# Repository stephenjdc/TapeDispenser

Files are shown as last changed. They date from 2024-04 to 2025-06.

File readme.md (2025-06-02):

# Kilnettle Shrine Souvenir Tape Dispenser



Blog post: https://stephencoyle.net/kilnettle

If you'd like to build your own [tape dispenser](https://stephencoyle.net/kilnettle), which tells you how much you've used, and blesses you afterwards, you have two choices.

1. Leave out a pencil and paper one night before bed, and hope that by the morning God will have written down the instructions.
2. Buy one from me. Maybe? Details coming soon(?)
3. Clone this repo, buy the required parts, a 3D printer, and get to work. [Here's an assembly tutorial](https://youtu.be/CnwMDydeqiA).

Please note that, while the dispenser does aim to fairly accurate, it's not perfectly accurate as it doesn't adjust for the amount of tape used. In the code I've just split the error, so it will tend to overshoot the measurement when a roll is full, and undershoot a bit when it's empty. Given we're only dealing with one-inch resolution, I feel like it's probably fine. You can tweak the code if you want to try and improve on this. There's also is a no-code way to tweak it, detailed below.

## License 
Feel free to make/reuse/modify this project for personal use. In the unlikely event that you're planning to spin up a large-scale production line to make thousands of these, I'd really recommend doing a few more revisions on the code and the models. In which case, I'm available at a very reasonable rate.

## Parts list

### Electronics
- 1× ESP8266 or similar (e.g. I used an ESP-12E)
- 1× IR photodiode (3mm)
- 1× IR LED (3mm)
- 2× 1k resistors
- 2× 10k resistors
- 1× 220Ω resistor
- 1× 2N3904 transistor (or similar)
- 1× LED (colour of your choice, I recommend red)
- 1× 20mm diameter speaker
- 1× 18mm × 12mm slide switch (or any that fits the space on the model)
- Battery clips for 2x AAA batteries

There are included KiCAD files which you can use to create a PCB for this, but point-to-point soldering can also work if you don't want to do that.

#### PCB Legend
| PCB Label | Component | Description |
|---|---|---|
| `R1` | `1K resistor` | |
| `R2` | `220R resistor` | |
| `R3` | `1K resistor` | |
| `R4` | `10K resistor` | |
| `R5` | `10K resistor` | |
| `D1` | `Photodiode` | Small black LED |
| `D2` | `IR LED` |  Small clear LED |
| `D3` | `Indicator LED` | Red LED |
| `LS1` | `Speaker` |  |
| `Q1` | `2N3904 Transistor` |  |
| `U1` | `ESP8266` |  |
| `J1` | `GND` |  |
| `J2` | `+3V` | |

### Dispenser body
#### These parts are 3D-printable (in the models folder)
- 1× tape dispenser body
- 1× tape dispenser lid (which holds the spool)
- 1× battery compartment cover
- 1× tape spool
- 1× "Greetings from Kilnettle" text

#### These parts are not 3D printable
- 1× 33mm × 5mm hacksaw blade (for tape cutter)
- 1x 25mm × 1mm steel rod (for example, cut from a large paperclip)
- 2× AAA batteries
- 1x roll of sticky tape with ~27mm inner diameter and ~56mm outer diameter. I used [this one](https://firstclassofficesupplies.com/product/stik-ie-clear-tape-refills/).

## Instructions
I'm gonna keep these fairly sparse, and following what I did. But there's no right way to do it. In the very unlikely event that you actually want to make one yourself, and run into trouble, feel free to message me with any questions. The [video version](https://youtu.be/CnwMDydeqiA) may also be more useful!

1. Flash the ESP-12E with the included sketch, _and data folder_. I used PlatformIO and would suggest you do too.
2. 3D print the included files.
3. Insert the battery clips into the slots in the battery container. Note which side has holes for the positive and negative tabs to slot into.
4. Fit the slider switch into the hole above the battery compartment. Either glue into place, or like I did, use a soldering iron to melt and smush the little nubs to fix it in place.
5. Fit the IR photodiode and LED into the holes on the sides of the lid. They should be a fairly tight fit; push them all the way in. I added a little drop of superglue to keep them fixed in place.
6. Add the speaker. It should click into place at the front of the body, though I added a little hot glue just to be sure. If you aren't using the PCB, it might be easier to add the transistor and resistor on or near the speaker itself, then tuck all that in with the speaker.
7. Solder some wires to the battery tabs and switch.
8. Follow the rest of the schematic to attach all the parts. If you aren't using the PCB, use the thinnest wire you feasibly can, and route the wires as best you can to allow the case to close. I'd recommend leaving a decent bit of slack, and regularly trying to fit the lid on to make sure all is fitting well.
9. Once that's done, I'd recommend testing it out[^1], so you can check the software is flashed properly before you finish fitting things into place.
10. Pop on the lid, if you're happy everything is working. The tabs at the back should clip into place in the case.
11. Superglue the section of hacksaw blade in place on the front of dispenser. Make sure to put the sharper side facing up, if there is one, so it cuts the tape nicely.
12. Attach the "Greetings from Kilnettle" text to the left side of the dispenser body (left when looking at the bladed end).
13. For the spool, thread the steel rod through the hole in its centre. Add a drop of glue and line it up so that it protrudes an equal amount on either side. It should then press fit into the tape, and you can set it into the dispenser.
14. Insert batteries (be careful to put them in the right way round), pop on the battery cover, and all being well, you should now be able to switch it on and enjoy your dispenser!

[^1]: You can easily test it without a spool, by waving your finger around in the spool cavity, making sure you block the IR beam a few times.

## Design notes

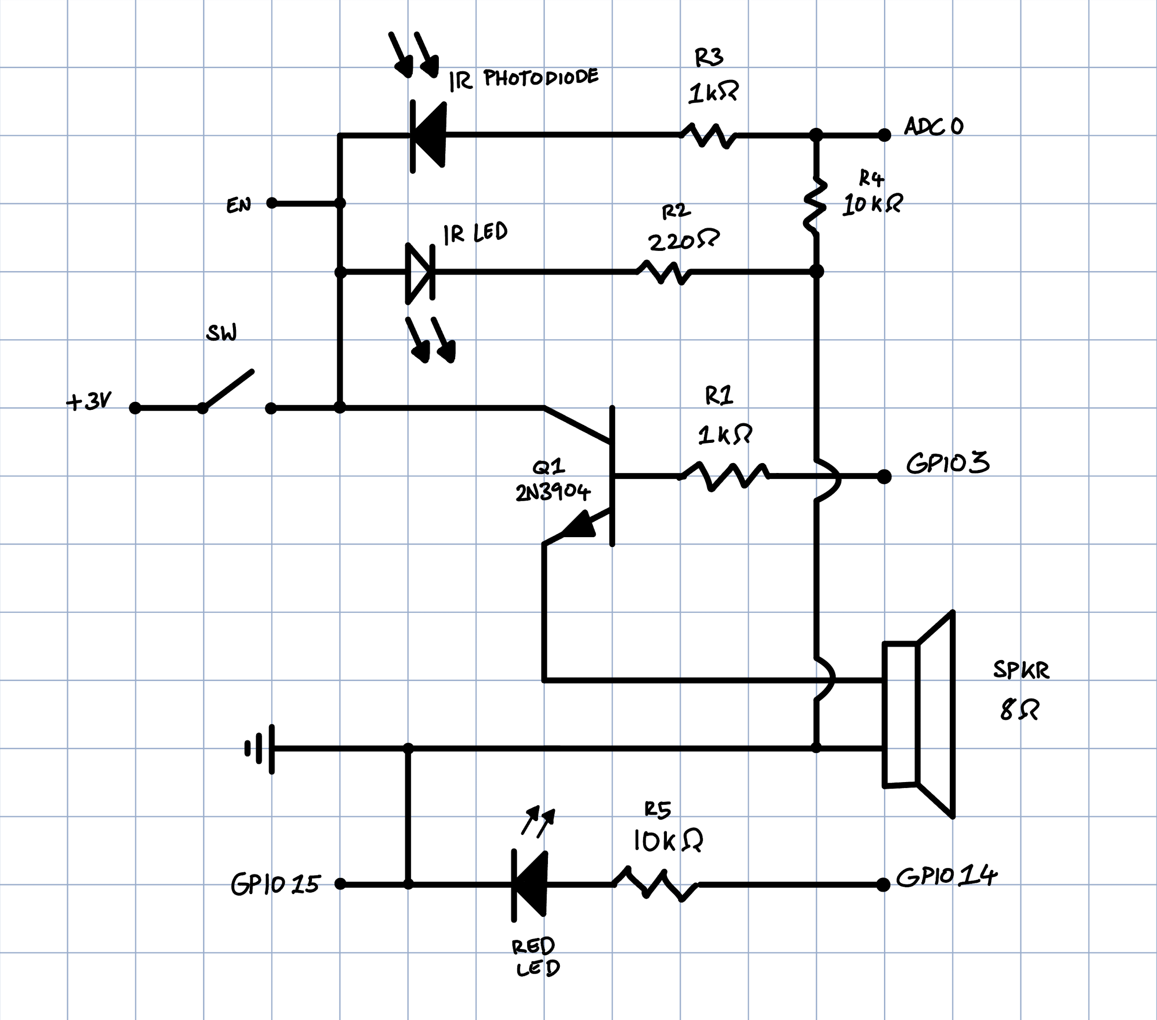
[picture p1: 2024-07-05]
pcb/schematic.png

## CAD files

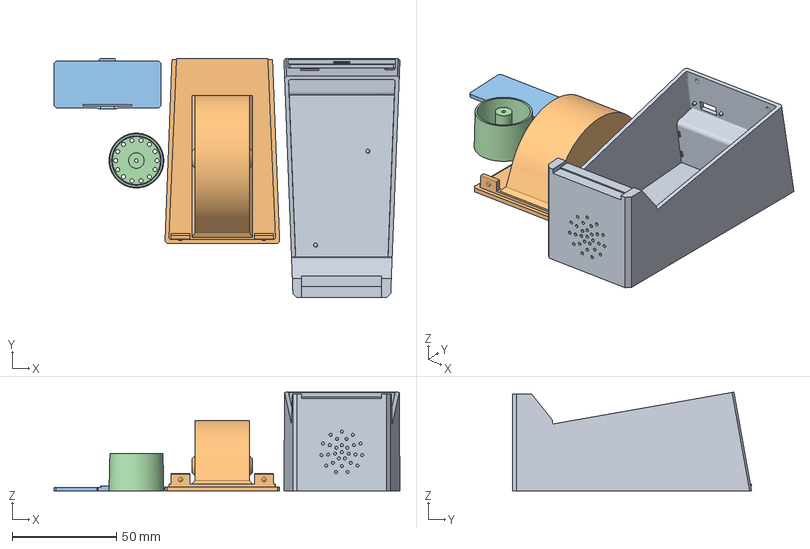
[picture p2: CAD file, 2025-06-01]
models/v2_models/All Parts Excl Text.3mf
166.2 x 115.0 x 47.5 mm
body_v3.stp
lid.stp
battery_door_v3.stp
spool.stp

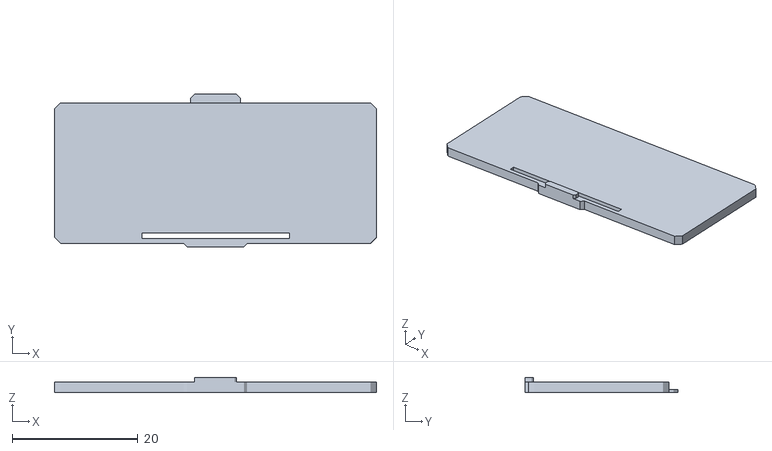
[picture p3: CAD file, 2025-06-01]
models/v2_models/battery_door.stl
51.3 x 24.3 x 2.36

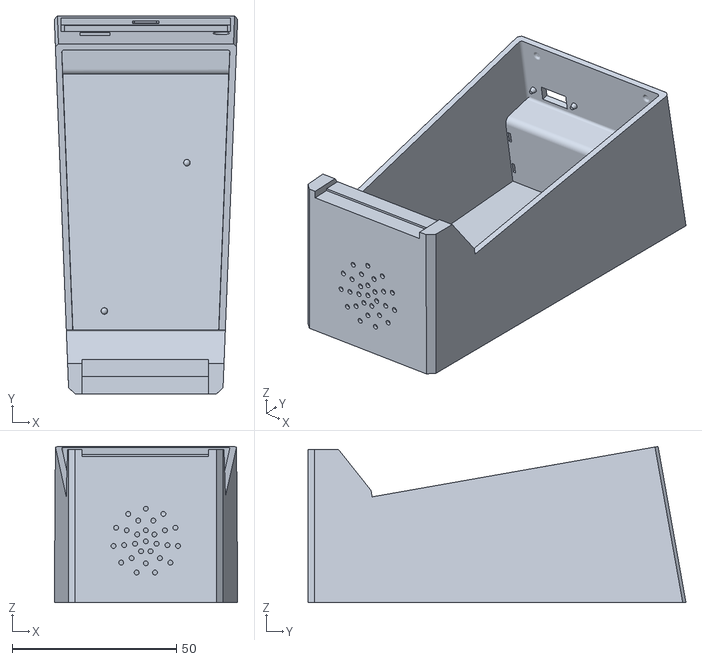
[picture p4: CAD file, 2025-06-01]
models/v2_models/body.stl
55.8 x 115.0 x 47.5

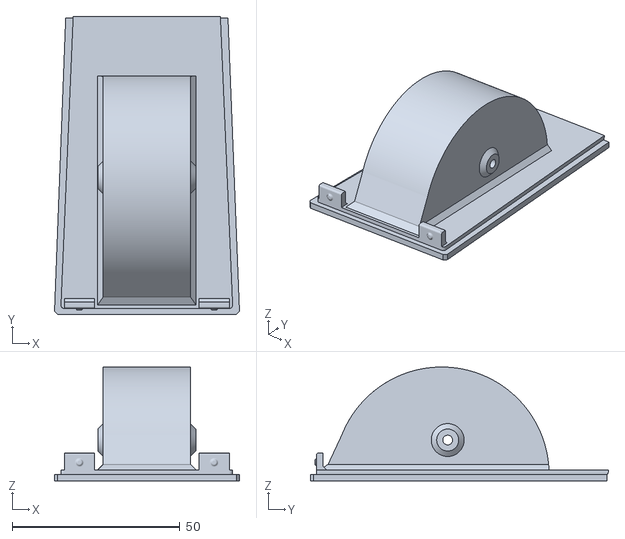
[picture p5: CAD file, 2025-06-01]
models/v2_models/lid.stl
55.1 x 88.9 x 33.9

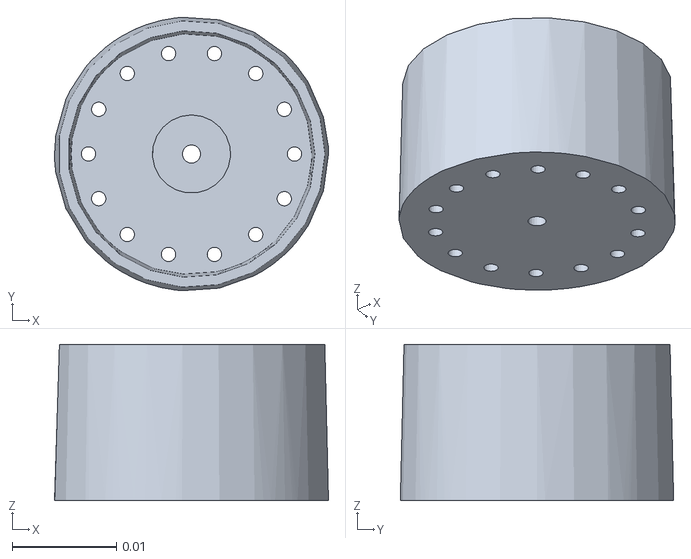
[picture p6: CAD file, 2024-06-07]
models/v2_models/spool.stl
0.0263 x 0.0262 x 0.015

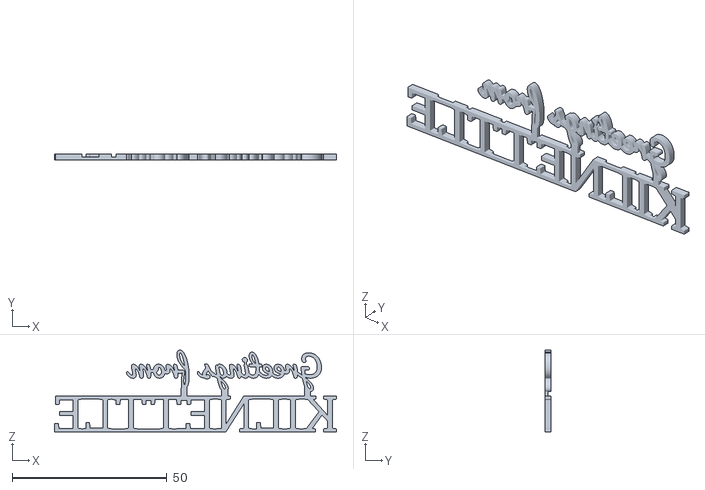
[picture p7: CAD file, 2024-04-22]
models/v2_models/greetings_text.stl
91.1 x 2.00 x 26.5

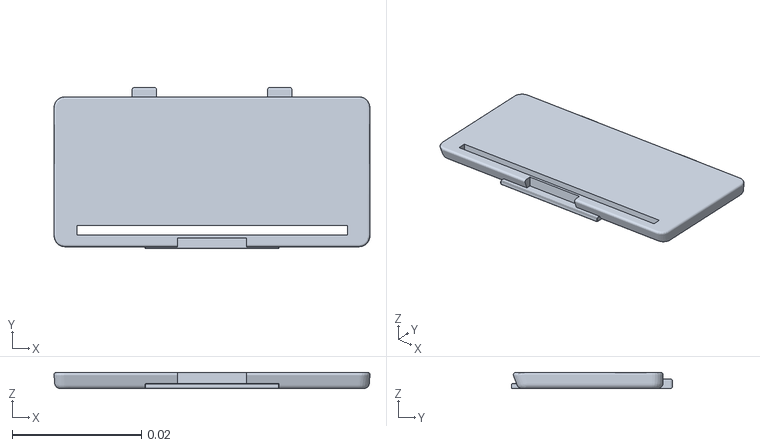
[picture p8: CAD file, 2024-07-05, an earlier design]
models/v1_models/battery_door.stl
0.0488 x 0.0249 x 0.0025

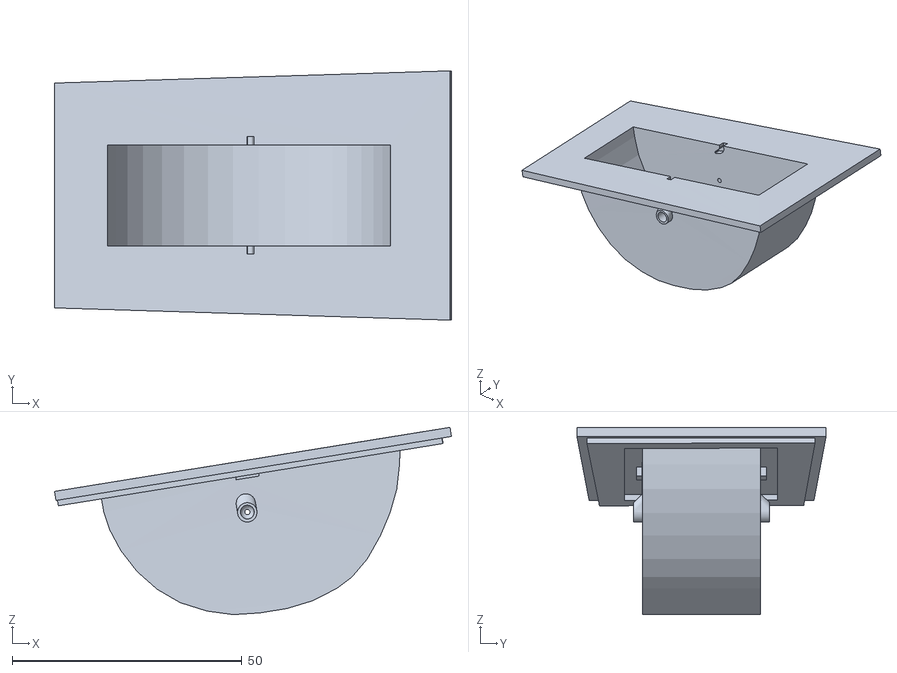
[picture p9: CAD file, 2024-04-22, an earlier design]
models/v1_models/dispenser_lid.stl
86.4 x 54.2 x 40.7

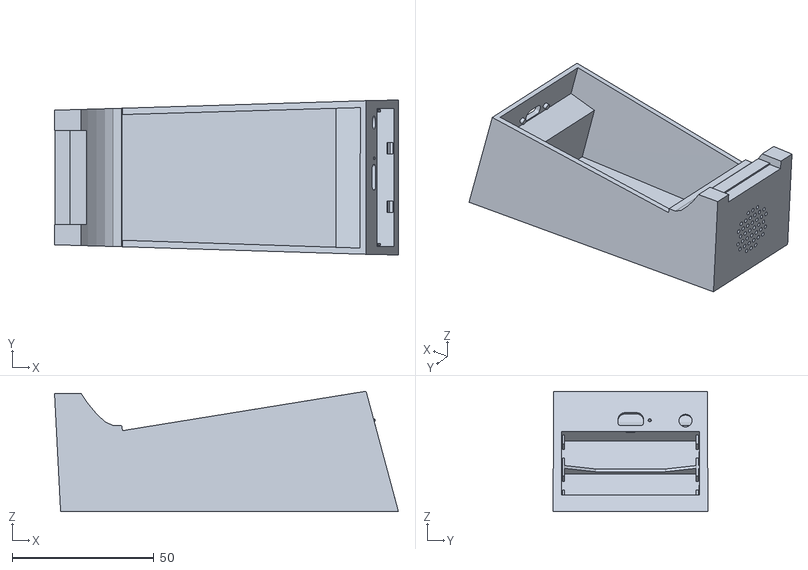
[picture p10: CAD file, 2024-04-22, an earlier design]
models/v1_models/dispenser_body.stl
121.5 x 54.7 x 42.5

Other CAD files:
models/v1_models/spool_13.stl
models/v1_models/spool_16.stl
models/v1_models/spool_15.stl

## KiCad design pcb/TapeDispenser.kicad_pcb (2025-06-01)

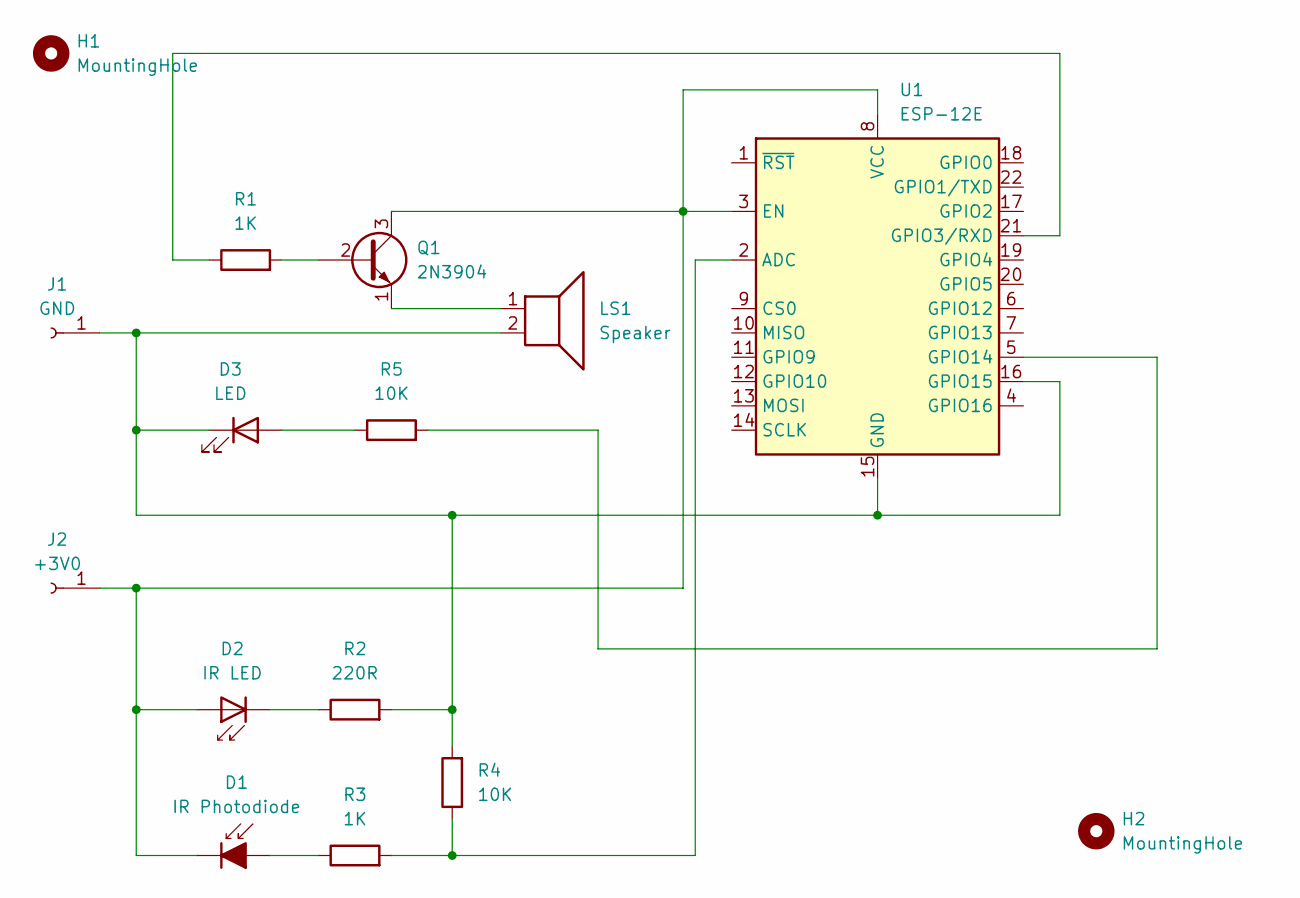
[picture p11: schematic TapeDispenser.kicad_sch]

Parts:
D1: IR Photodiode; SolderWire-0.5sqmm_1x02_P4.6mm_D0.9mm_OD2.1mm
D2: IR LED; SolderWire-0.5sqmm_1x02_P4.6mm_D0.9mm_OD2.1mm
D3: LED; SolderWire-0.5sqmm_1x02_P4.6mm_D0.9mm_OD2.1mm
H1, H2: MountingHole; MountingHole_2.2mm_M2
J1: GND; SolderWire-0.5sqmm_1x01_D0.9mm_OD2.1mm
J2: +3V0; SolderWire-0.5sqmm_1x01_D0.9mm_OD2.1mm
LS1: Speaker; SolderWire-0.5sqmm_1x02_P4.6mm_D0.9mm_OD2.1mm
Q1: 2N3904; TO-92_Inline
R1, R3: 1K; R_Axial_DIN0207_L6.3mm_D2.5mm_P10.16mm_Horizontal
R2: 220R; R_Axial_DIN0207_L6.3mm_D2.5mm_P10.16mm_Horizontal
R4, R5: 10K; R_Axial_DIN0207_L6.3mm_D2.5mm_P10.16mm_Horizontal
U1: ESP-12E

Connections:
unnamed: D1.2 (A), R3.1
unnamed: D1.1 (K), D2.2 (A), J2.1, Q1.3 (C), U1.3 (EN), U1.8 (VCC)
unnamed: D2.1 (K), R2.1
unnamed: D3.2 (A), R5.1
unnamed: D3.1 (K), J1.1, LS1.2, R2.2, R4.2, U1.15 (GND), U1.16 (GPIO15)
unnamed: Q1.2 (B), R1.2
unnamed: LS1.1, Q1.1 (E)
unnamed: R3.2, R4.1, U1.2 (ADC)
unnamed: R1.1, U1.21 (GPIO3/RXD)
unnamed: R5.2, U1.5 (GPIO14)

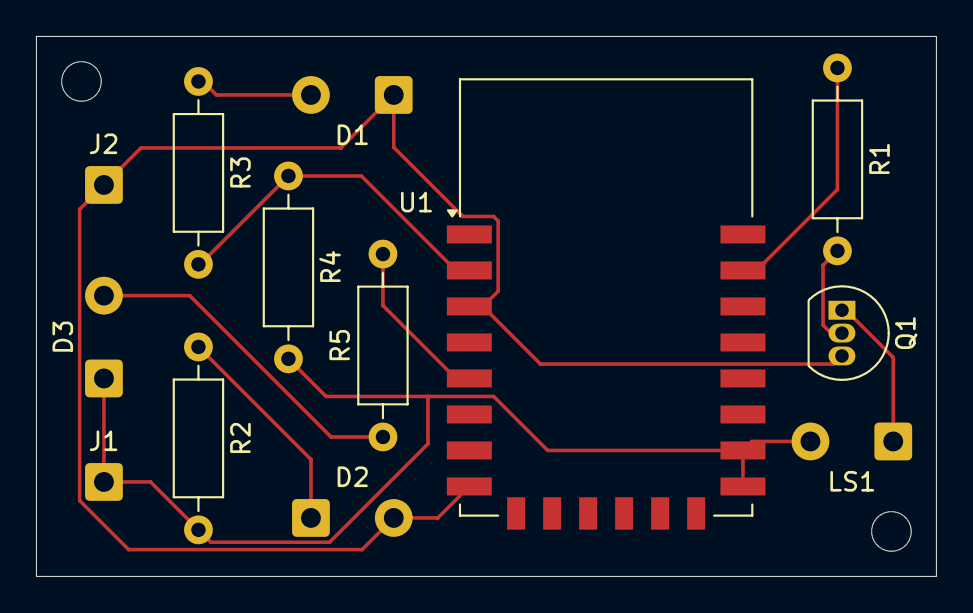
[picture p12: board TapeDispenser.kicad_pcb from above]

Board: 2 copper layers, 50.0 x 30.0 mm, 15 parts (0 on the bottom side), 10 nets.

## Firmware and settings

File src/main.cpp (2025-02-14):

#include <Arduino.h>
#include "AudioFileSourceICYStream.h"
#include "AudioFileSourceBuffer.h"
#include "AudioGeneratorMP3.h"
#include "AudioOutputI2SNoDAC.h"
#include "AudioFileSourceSPIFFS.h"
#include <ESP8266WiFi.h>
#include <I2S.h>

/*
  NOTES

  'events' are when the signal from the IR sensor changes
  i.e. both HIGH->LOW and LOW->HIGH transitions. So there
  are twice as many events per rotation as there are notches
  in the spool.

  Since we're measuring an analog value, and to avoid
  excess events, we measure when the sensor value crosses an
  upper threshold or lower threshold. When one is crossed, we
  report an event, then wait until the other threshold is
  crossed before reporting another event.

*/

//////
//////
// Tape Config
//////
//////
int inchesPerFoot = 12;
/*
  There's no practical limit on the amount of tape we can measure, but with the included
  audio files, the maximum length we can achieve is 11ft 11in.
*/
int maximumInches = 143;
float millimetresPerInch = 25.4;
/*
  Ideally, the distance from the centerpoint of the spool
  to 1/2 way along the width of the tape. This splits the difference in errors;
  undershoot slightly when full, and overshoot slightly when near-empty. This will
  be well within 1-inch resolution.
*/
float tapeRadiusInMillimetres = 22.5;
/*
  The number of openings in the spool, i.e. the number of times the 
  IR beam will get broken per 1 revolution.
*/
int notchesInSpool = 16;
/*
  For ease of configuration, we'll set these values during setup.
  For efficiency's sake, since they won't change during operation,
  we won't bother calculating them every time.
*/
float circumference;
float millimetresPerEvent;
//////
//////


//////
//////
// Rotation Calculation
//////
//////
/*
  There will be twice as many events per rotation as there are notches in the spool,
  because an event means both the transition LOW->HIGH and HIGH->LOW.
*/
int eventsPerFullRotation = notchesInSpool * 2; 
int minimumEventsToAnnounce = 3;
int eventCounter = 0;
unsigned long timeOfLastEvent = 0;
float eventTimeoutInMilliseconds = 750;
//////
//////


//////
//////
// Debug
//////
//////
#define STATE_LED_PIN D5
#define WARN_LED_PIN D7
bool ledState = false;
//////
//////


//////
//////
// IR Sensing
//////
//////
#define IR_SENSOR_PIN A0 
int irLowThreshold = 30;
int irHighThreshold = 100;
bool passedHighThreshold = false;
bool passedLowThreshold = false;
// To debounce IR pulses
float minimumTimeBetweenEvents = 2;
//////
//////


//////
//////
// Audio Filenames
//////
//////
String filePrefix = "/";
String fileSuffix = ".mp3";
String youHaveUsedFile = filePrefix + "yhu" + fileSuffix;
String godBlessYouFile = filePrefix + "gby" + fileSuffix;
String inchFile = filePrefix + "inch" + fileSuffix;
String inchesFile = filePrefix + "inches" + fileSuffix;
String footFile = filePrefix + "foot" + fileSuffix;
String feetFile = filePrefix + "feet" + fileSuffix;
String usedTooMuch = filePrefix + "curse" + fileSuffix;
//////
//////

//////
//////
// Function Declarations
//////
//////
String filenameForNumber(int number);
AudioFileSourceSPIFFS* fileForName(String name);
int eventsToInches(int eventCount);
bool eventsFinished();
void tapeMoved();
void resetCounters();
void startAnnouncement();
void queueBlessing(int feet, int inches);
void printBlessing(int feet, int inches);
void queueCurse();
void printCurse();
void eventLoop();
void sensorLoop();
void playQueuedAudio();
void playbackLoop();
void resetPlayback();
void addToQueue(String filename);
//////
//////

//////
//////
// Audio playback
//////
//////
AudioGeneratorMP3 *mp3;
AudioFileSourceSPIFFS *file;
AudioOutputI2SNoDAC *out;

String audioFiles[6];
int queueArraySize = 0;
int queuePlaybackPosition = 0;
bool playbackInProgress = false;
uint32_t i2sACC;
uint16_t err;
//////
//////

void testAudio() {
  queueBlessing(1, 3);
  playQueuedAudio();
}

void setup()
{
  circumference = tapeRadiusInMillimetres * PI * 2;
  millimetresPerEvent = circumference/eventsPerFullRotation;

  WiFi.mode(WIFI_OFF);
  Serial.begin(75200);
  delay(1000);
  SPIFFS.begin();
  pinMode(WARN_LED_PIN, OUTPUT);
  pinMode(STATE_LED_PIN, OUTPUT);

  out = new AudioOutputI2SNoDAC();
  out->SetOversampling(200);
  out->SetGain(2.0);
  Serial.println("Hello! How's the son?");

  // Turn on LED when ready
  digitalWrite(STATE_LED_PIN, HIGH);

  // delay(1000);
  // testAudio();
}

void loop() {
  playbackLoop();

  // if audio is playing, skip the rest of the loop.
  if (playbackInProgress) { return; }
  sensorLoop();
  eventLoop();
}

void sensorLoop() {
  int value = analogRead(IR_SENSOR_PIN);

  if (value < irLowThreshold) {
    if (!passedLowThreshold) {
      tapeMoved();
    }
    passedLowThreshold = true;
    passedHighThreshold = false;
  } else if (value > irHighThreshold) {
    if (!passedHighThreshold) {
      tapeMoved();
    }
    passedLowThreshold = false;
    passedHighThreshold = true;
  }
}

/*
  Runs each loop
  Resets event counter if timeout has elapsed
  Triggers audio playback if required
*/ 
void eventLoop() {
  if (timeOfLastEvent == 0) {
    return;
  }

  if (millis() - eventTimeoutInMilliseconds < timeOfLastEvent) {
    return;
  }

  /*
    If the counter is above the minimum threshold, play announcement
    and reset. If it's below the threshold, just reset.
  */
  if (eventCounter > minimumEventsToAnnounce) {
    playbackInProgress = true;
    digitalWrite(STATE_LED_PIN, LOW);
    startAnnouncement();
    resetCounters();
  } else {
    resetCounters();
  }
}

void showDebugLEDs(bool debounced) {
  digitalWrite(WARN_LED_PIN, debounced);

  if (ledState) {
    digitalWrite(STATE_LED_PIN, LOW);
    ledState = false;
  } else {
    digitalWrite(STATE_LED_PIN, HIGH);
    ledState = true;
  }
}

/*
  Triggered once per IR event
  Increments rotation event counter and time
*/
void tapeMoved() {
  unsigned long time = millis();
  // Debounce signal from IR led
  if ((time - timeOfLastEvent) < minimumTimeBetweenEvents) {
    // showDebugLEDs(true);
    return;
  } 
  // showDebugLEDs(false);

  // Set event properties
  eventCounter += 1;  
  timeOfLastEvent = time;
}

/*
  Convert the specified eventCount to the nearest integer inch
*/
int eventsToInches(int eventCount) {
  float inches = (millimetresPerEvent * eventCount) / millimetresPerInch;
  // Cheap and cheerfully round to the nearest int
  inches += 0.5;
  return (int)inches;
}

void startAnnouncement() {
  int inches = eventsToInches(eventCounter - 1);
  int feet = inches / inchesPerFoot;
  int remainingInches = inches % inchesPerFoot;

  if (inches > maximumInches) {
    queueCurse();
    printCurse();
  } else {
    queueBlessing(feet, remainingInches);
    printBlessing(feet, remainingInches);
  }

  playQueuedAudio();
}

void resetCounters() {
  eventCounter = 0;
  timeOfLastEvent = 0;
}

void queueCurse() {
  addToQueue(usedTooMuch);
}

void printCurse() {
  Serial.println("You have wasted a load of sticky tape. Go to confession.");
}

/*
  Queue the relevant audio files for the measure
  tape length.
*/
void queueBlessing(int feet, int inches) {
  addToQueue(youHaveUsedFile);

  if (feet == 1) {
    addToQueue(filenameForNumber(feet));
    addToQueue(footFile);
  } else if (feet > 0) {
    addToQueue(filenameForNumber(feet));
    addToQueue(feetFile);
  }

  if (inches == 1) {
    addToQueue(filenameForNumber(inches));
    addToQueue(inchFile);
  } else if (inches > 0) {
    addToQueue(filenameForNumber(inches));
    addToQueue(inchesFile);
  }
  
  addToQueue(godBlessYouFile);
}

void addToQueue(String filename) {
  audioFiles[queueArraySize] = filename;
  queueArraySize++;
}

/*
  A mostly-debug function, to print the measurement to Serial, instead of
  playing audio.
*/
void printBlessing(int feet, int inches) {
  Serial.println("");
  Serial.println("----");

  Serial.print("You have used ");

  if (feet == 1) {
    Serial.print(feet);
    Serial.print(" foot ");
  } else if (feet > 0) {
    Serial.print(feet);
    Serial.print(" feet ");
  }

  if (inches == 1) {
    Serial.print(inches);
    Serial.print(" inch ");
  } else if (inches > 0) {
    Serial.print(inches);
    Serial.print(" inches ");
  }

  Serial.println("of sticky tape. God bless you.");
  Serial.print("@");
  Serial.println(millis());
  Serial.println("----");
  Serial.println("");
}

//////
//////
// Audio playback
//////
//////

// Generate the filename for number audioclips
String filenameForNumber(int number) {
    return filePrefix + String(number) + fileSuffix;
}

AudioFileSourceSPIFFS* fileForName(String name) {
  return new AudioFileSourceSPIFFS(name.c_str());
}

void writeDAC(uint16_t DAC) {
  for (uint8_t i=0;i<32;i++) {
    i2sACC=i2sACC<<1;

    if(DAC >= err) {
      i2sACC|=1;
      err += 0xFFFF-DAC;
    } else {
      err -= DAC;
    }
  }

  i2s_write_sample(i2sACC);
}

void startPlayback() {
  // Reduce pop at start of audio
  for (int j=1000;j>700;j--) {
    writeDAC(0x8000-32767*j/1000);
  }
  mp3->begin(fileForName(audioFiles[queuePlaybackPosition]), out);
}

void stopPlayback() {
  // Reduce pop at end of audio
  for (int j=0;j<1000;j++) {
    writeDAC(0x8000-32767*j/1000);
  }
  mp3->stop();
}

void playbackLoop() {
  if (!mp3) { return; }
  if (!mp3->isRunning()) { return; }
  if (mp3->loop()) { return; }

  /* If the file is finished playing, try moving onto the next file until there are none left. */
  if (queuePlaybackPosition < queueArraySize - 1) {
    queuePlaybackPosition++;
    stopPlayback();
    startPlayback();
  } else {
    stopPlayback();
    resetPlayback();
  }
}

void playQueuedAudio() {
  mp3 = new AudioGeneratorMP3();
  // Start playing the first audio file in the queue.
  mp3->begin(fileForName(audioFiles[queuePlaybackPosition]), out);
}

void resetPlayback() {
  queueArraySize = 0;
  queuePlaybackPosition = 0;
  mp3 = NULL;
  playbackInProgress = false;
  digitalWrite(STATE_LED_PIN, HIGH);
  Serial.println("Will you have another cup of tea?");
}

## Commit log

2024-03-08 Changed from interrupt to polling analog value
2024-04-22 New audio files, better sensor algorithm
    + other improvements to code
2024-04-22 Calibration, disabled debug code, other tweaks
2024-04-22 Added 3D models and readme, cleanup
    [battery_door.stl, dispenser_body.stl, dispenser_lid.stl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]
2024-06-07 Updated battery door, new spool design
    [battery_door.stl, spool_13.stl, spool_14.stl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]
2024-07-05 Added schematic, instructions and updated battery model.
    [battery_door.stl]
2025-06-01 updated models and instructions
    [TapeDispenser-B_Cu.gbr, TapeDispenser-B_Mask.gbr, TapeDispenser-B_Paste.gbr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]
2025-06-01 Create All Parts Excl Text.3mf
    [All Parts Excl Text.3mf]
2025-07-09 More reliable spool design
    [spool.stl]
